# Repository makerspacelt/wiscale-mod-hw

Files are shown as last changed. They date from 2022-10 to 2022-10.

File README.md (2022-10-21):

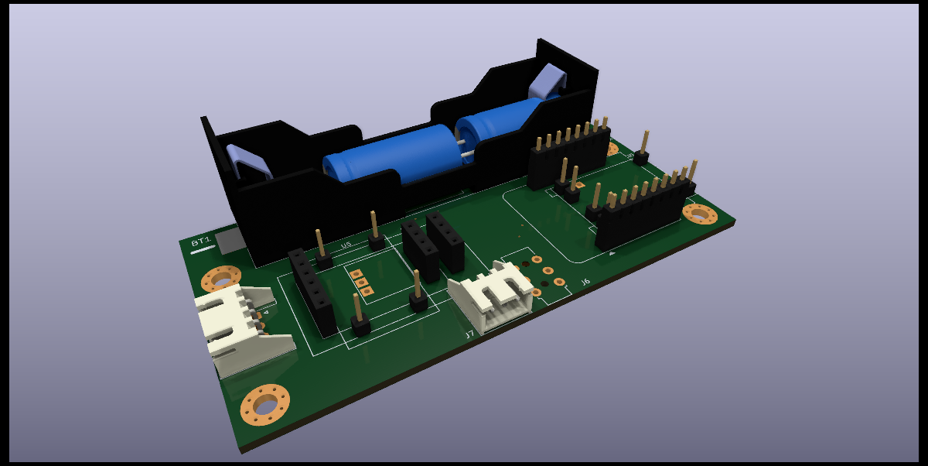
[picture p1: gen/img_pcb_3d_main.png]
PCB 3d main


This is ESP8266 and HX711 based weight monitoring device.

* Designed from commonly available aliexpress modules.
* Supports multiple load cells.
* Can be populated with 18650 battery
* Can be operated in ultra low power mode

Dev NOTE: before commit, run `./kibot.sh` to regenerate documentation, bom, gerbers and other assets.

* [schematics.pdf](gen/schematics.pdf)
* [pcb.pdf with dimensions](gen/pcb.pdf)
* [pcb_bottom.pdf for toner transfer](gen/pcb_bottom.pdf)
* [ibom.html](gen/bom_ibom.html)
* [gerbers.zip](gen/gerbers/gerbers.zip)

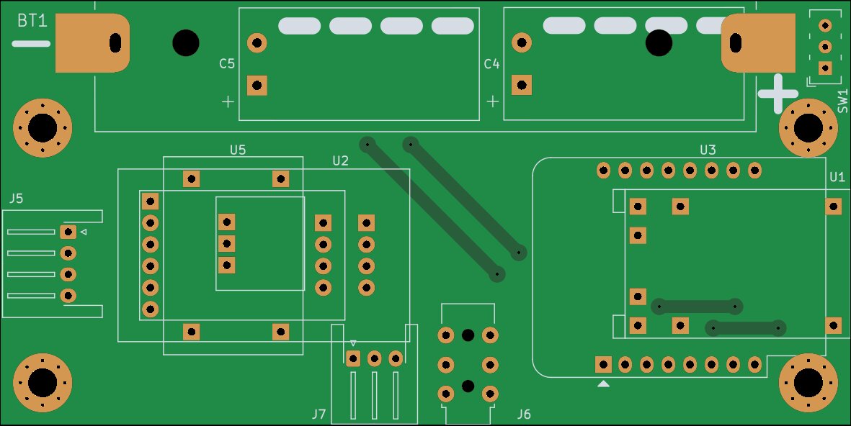
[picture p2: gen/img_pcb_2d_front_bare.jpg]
PCB 2d front bare

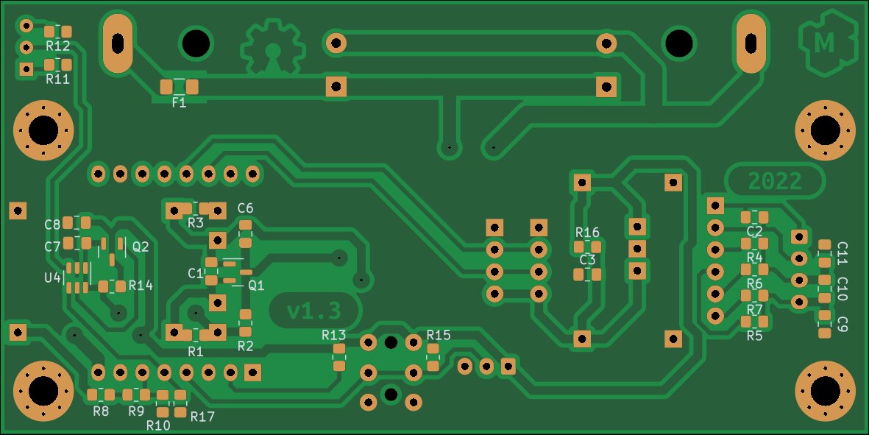
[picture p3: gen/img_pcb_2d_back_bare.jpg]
PCB 2d back bare


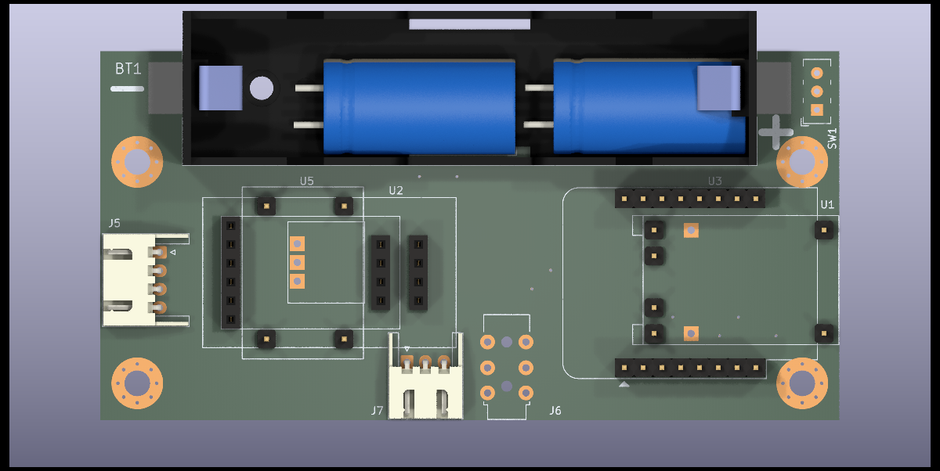
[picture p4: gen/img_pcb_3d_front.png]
PCB 3d front


## Normal operation

The circuit should be powered via a USB connector on the LiPo charger unless
battery support and low-power sleep is not used.

## Assembly and hardware configuration notes

### LiPo charger

Chargers(U1) with and without protection can be used. To use a charger without
protection that does not have separate power output pins - R1 needs to be
shorted out with a wire or zero ohms resistor.

For applications not requiring batteries whole LiPo charger section can be
omitted including components U1,Q1,BT1,F1,C1,C4,C5,C6. That requires that
the circuit be powered via a USB connector on the WeMos D1 mini module.

### Low-power sleep

A timer is equipped with selectable(SW1) wake-up settings(R11 and R12).

For applications that do not require a low-power sleep timer can be bypassed
by shorting out R14. Optionally components U3,C7,Q2,SW1,R11,R12 can be
omitted in assembly.

### Boost converter for ADC

Tests show that the circuit works down to about 2.7V without the need for
boosting voltage for ADC. Following that - the boost converter(U5) can be
omitted and R16 shorted out to bypass it.

### ADC configuration

To reduce noise on measurements capacitors(C9,C10,C11) on ADC input there
placed. As a side effect, they slow down reading settling time after weight change.
Removing these capacitors will give a fast reading but increase spread
by about 3 times.

Populating all of the R4,R5,R6,R7 links gives the ability to choose an ADC
amplifier and gain purely via software. What are the drawbacks of this
approach are unclear to me but there is an option to disconnect unused
amplifier by removing either R4 and R5 or R6 and R7 links.

## Software notes:

* keep D0 as input at all times for compatibility with older hardware (v1.0).

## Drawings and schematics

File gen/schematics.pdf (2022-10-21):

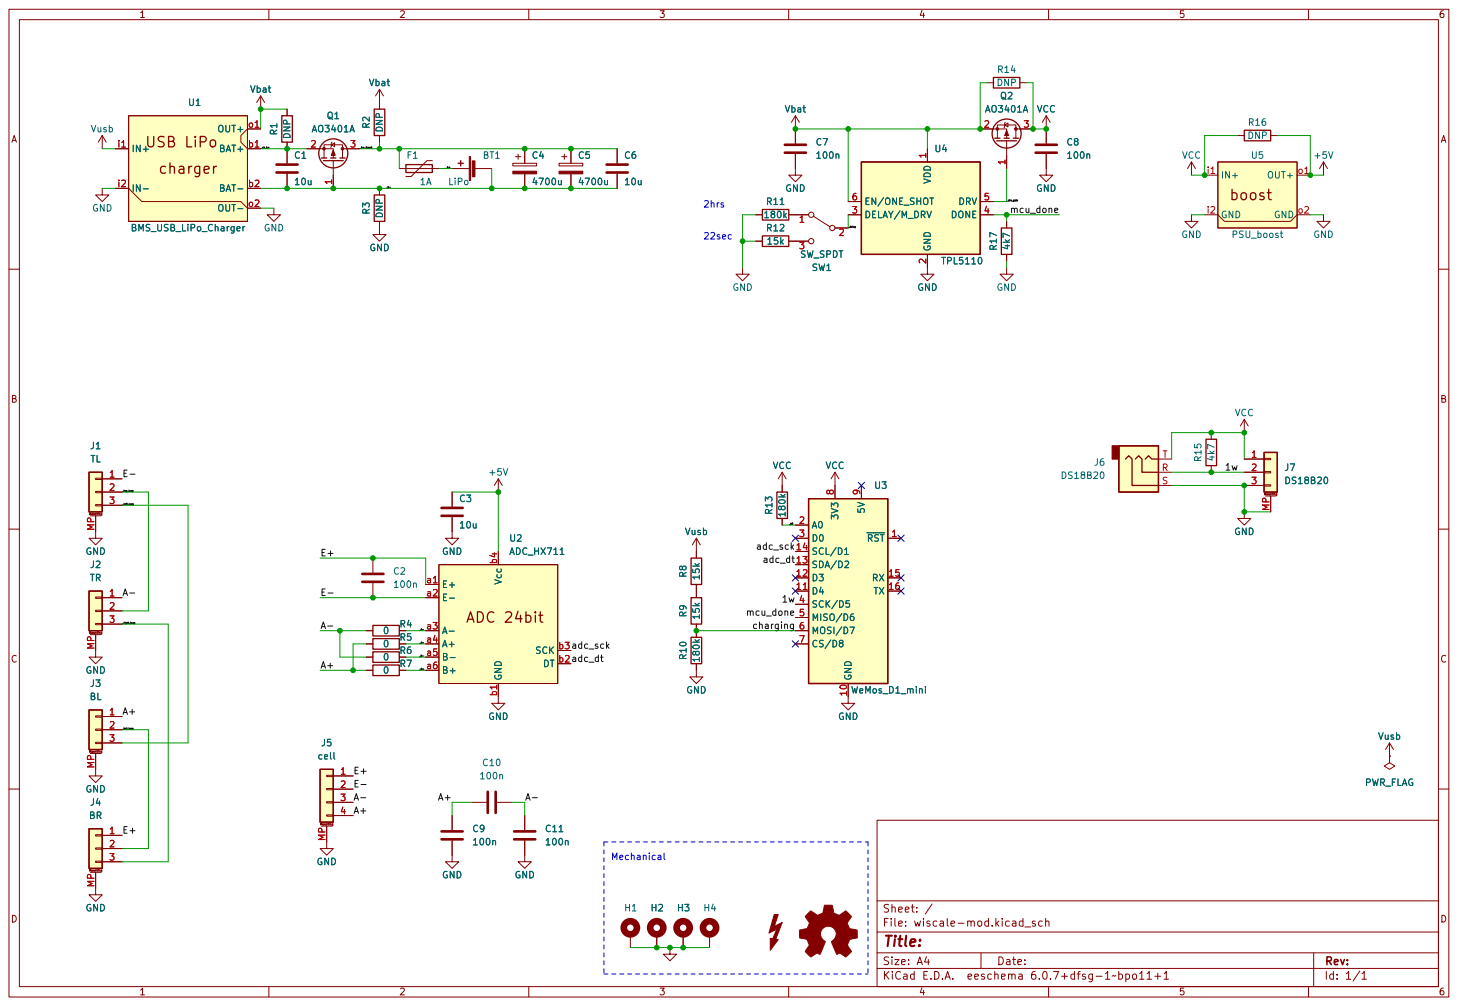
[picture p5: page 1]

2 DELAY/M_DRV 3 DONE 4 DRV 5 EN/ONE_SHOT 6 U4TPL5110 GND GND R17 4k7 C7
100n GND
2hrs 22sec Mechanical

2 DELAY/M_DRV 3 DONE 4 DRV 5 EN/ONE_SHOT 6 GND R17 4k7 C7

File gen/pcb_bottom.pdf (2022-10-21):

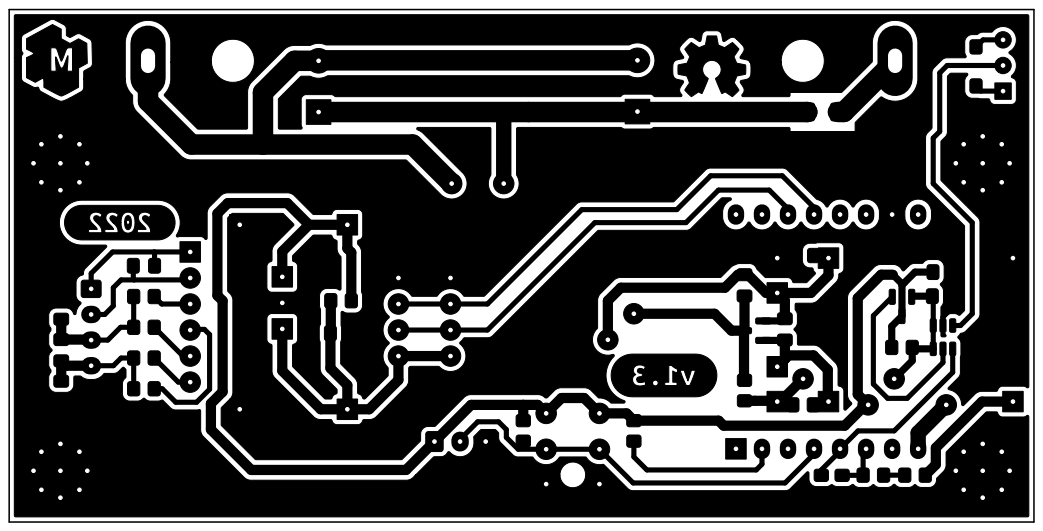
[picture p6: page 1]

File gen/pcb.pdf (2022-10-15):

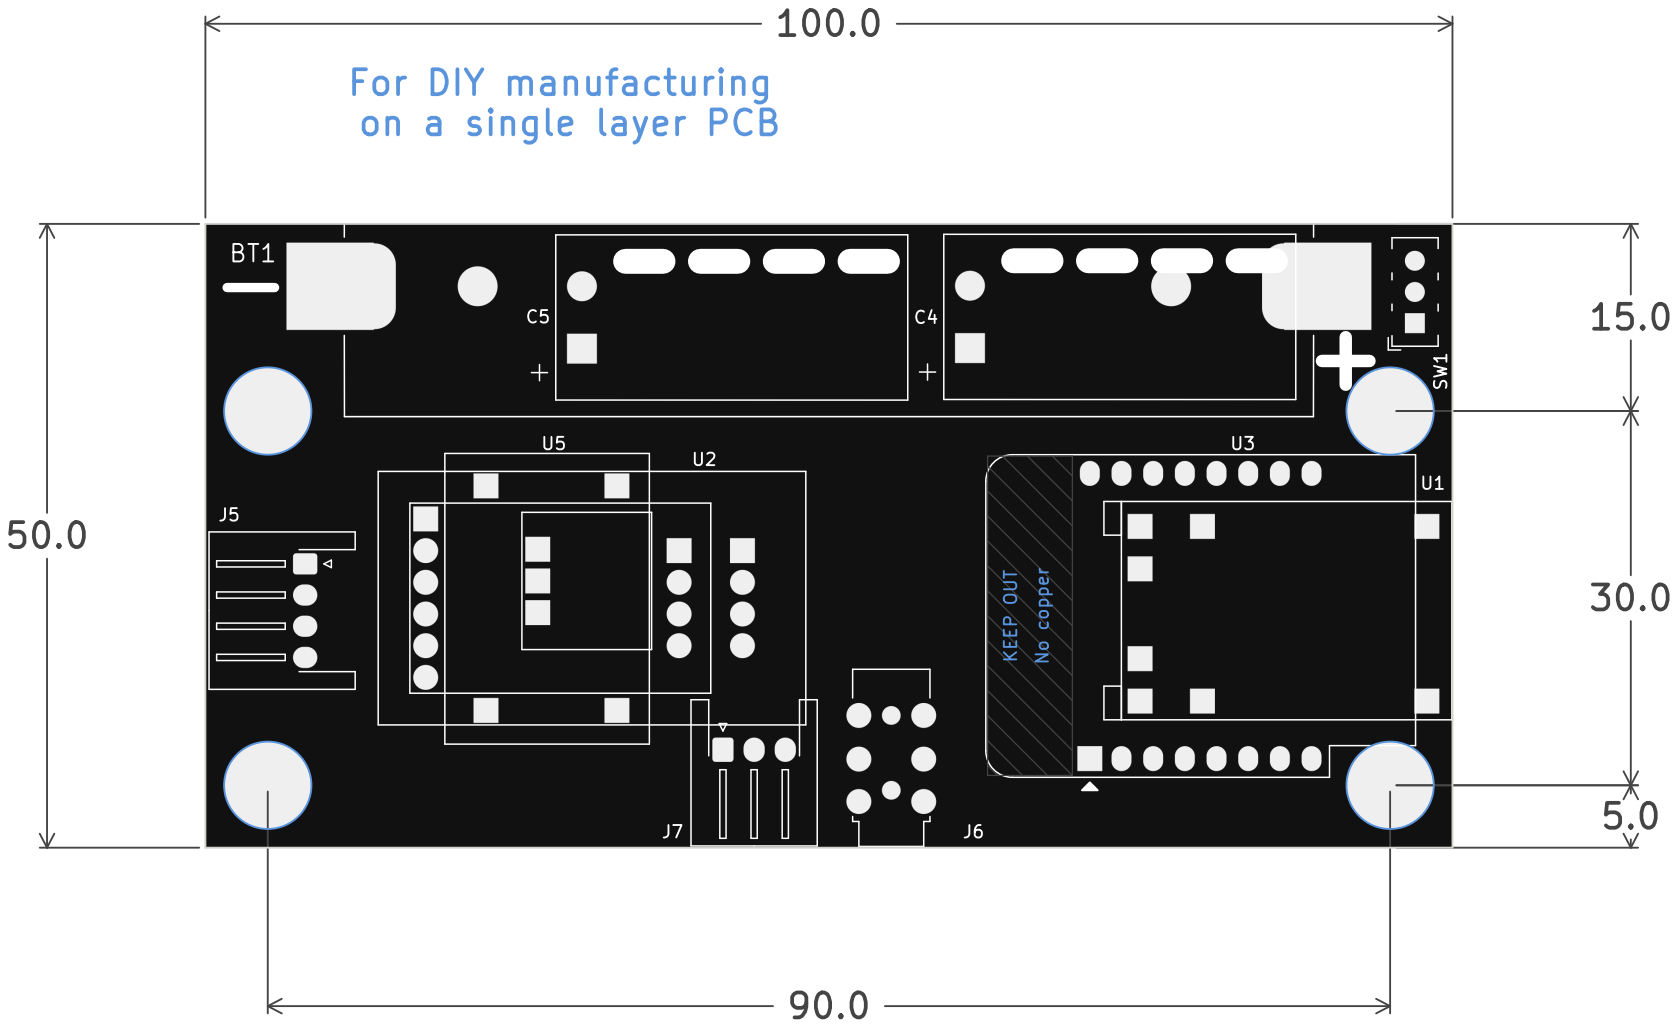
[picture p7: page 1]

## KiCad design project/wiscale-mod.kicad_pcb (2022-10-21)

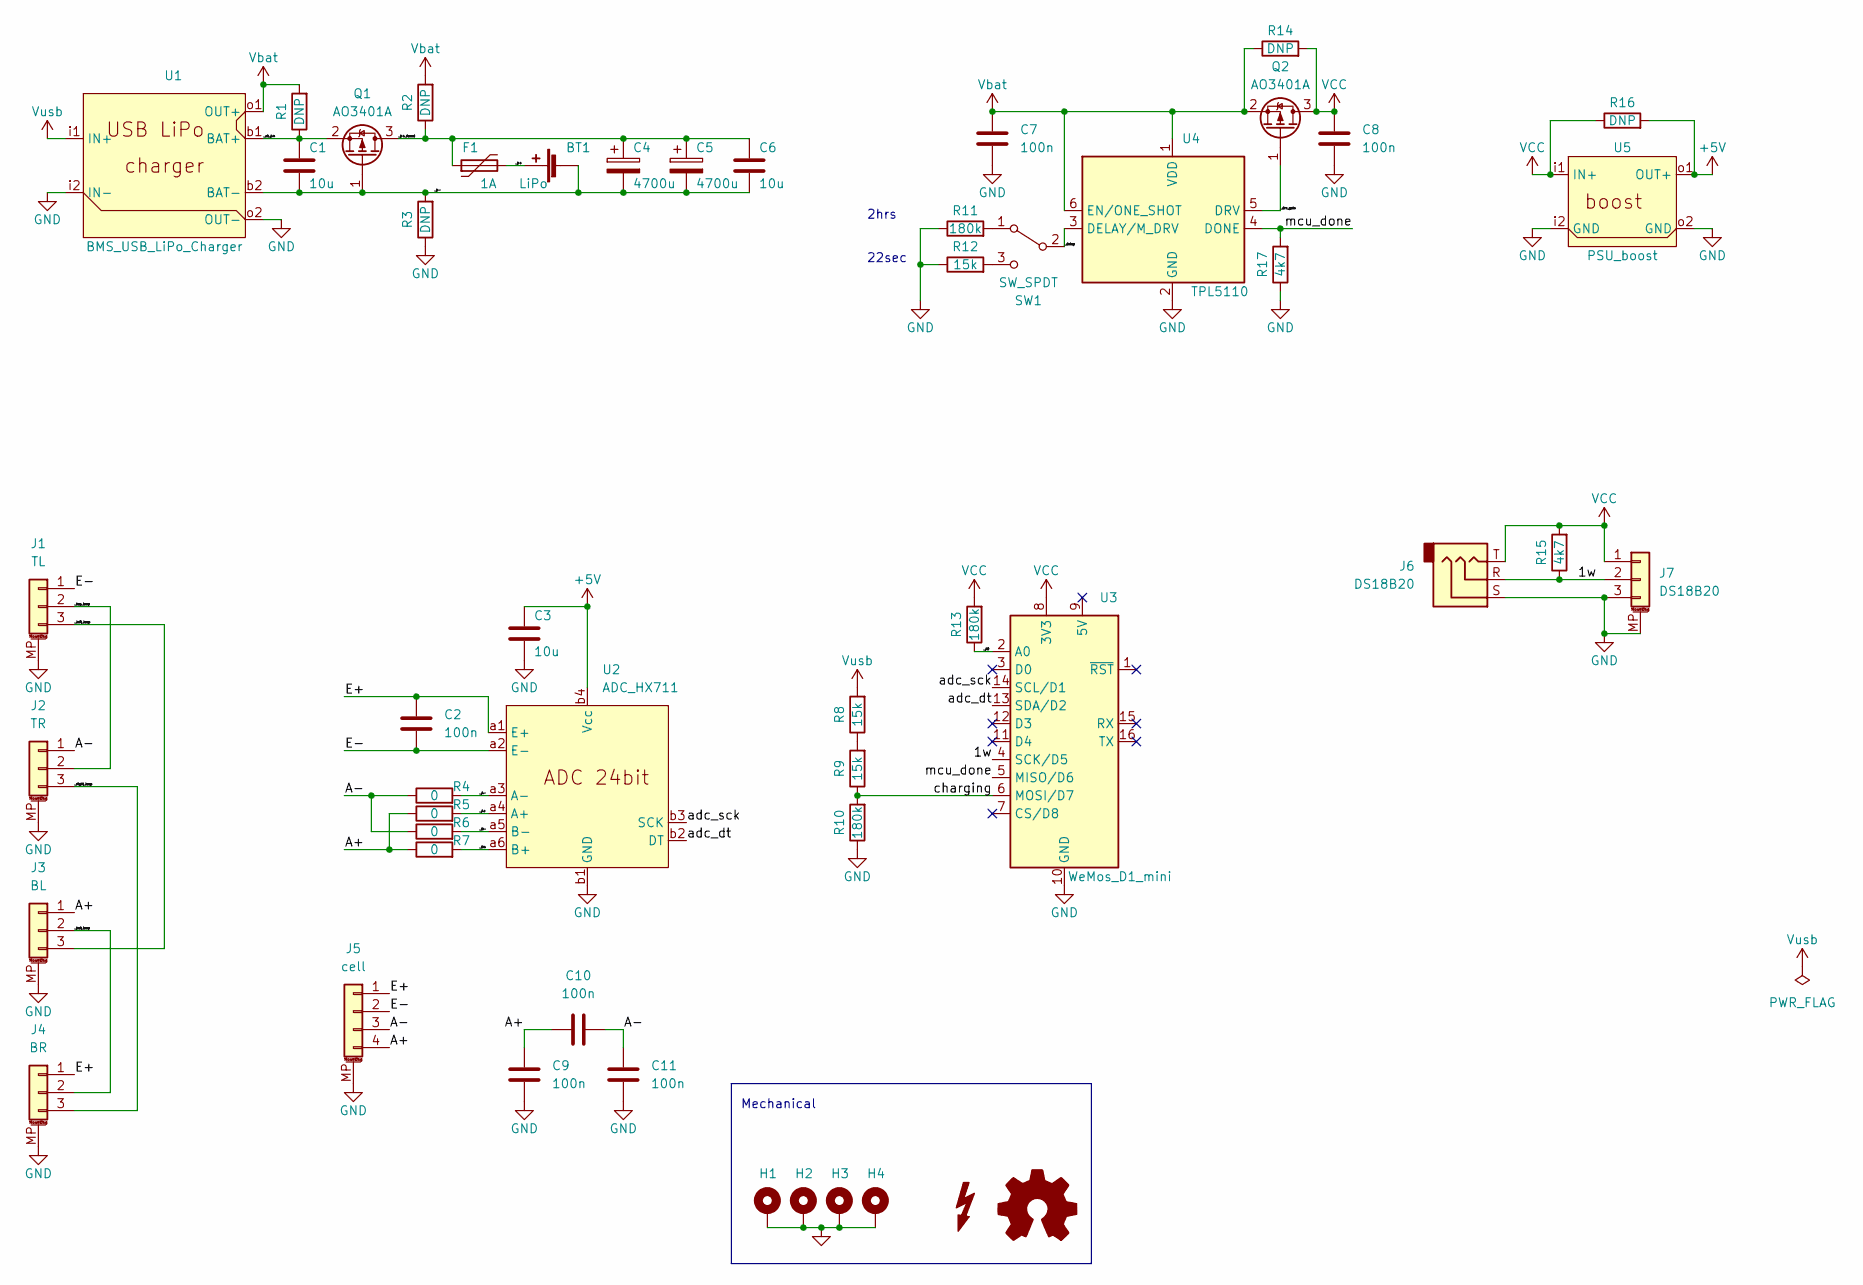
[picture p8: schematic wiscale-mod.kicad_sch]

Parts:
BT1: LiPo; BAT_BH-18650-PC
C1, C3, C6: 10u; C_0805_2012Metric_Pad1.18x1.45mm_HandSolder
C2, C7, C8, C9, C10, C11: 100n; C_0805_2012Metric_Pad1.18x1.45mm_HandSolder
C4, C5: 4700u; CP_Radial_D13.0mm_P5.00mm_L26.0mm
F1: 1A; Fuse_1206_3216Metric_Pad1.42x1.75mm_HandSolder
H1, H2, H3, H4: MountingHole_Pad; MountingHole_3.5mm_Pad_Via
J1: TL; JST_XH_S3B-XH-A-1_1x03_P2.50mm_Horizontal
J2: TR; JST_XH_S3B-XH-A-1_1x03_P2.50mm_Horizontal
J3: BL; JST_XH_S3B-XH-A-1_1x03_P2.50mm_Horizontal
J4: BR; JST_XH_S3B-XH-A-1_1x03_P2.50mm_Horizontal
J5: cell; JST_XH_S4B-XH-A-1_1x04_P2.50mm_Horizontal
J6: DS18B20; Jack_3.5mm_Horizontal
J7: DS18B20; JST_XH_S3B-XH-A-1_1x03_P2.50mm_Horizontal
LOGO1: logo_kms_small; logo_kms_small_copper
LOGO2: Logo_Open_Hardware_Small; OSHW-Symbol_6.7x6mm_Copper
Q1, Q2: AO3401A; SOT-23
R1, R2, R3, R14, R16: DNP; R_0805_2012Metric_Pad1.20x1.40mm_HandSolder
R4, R5, R6, R7: 0; R_0805_2012Metric_Pad1.20x1.40mm_HandSolder
R8, R9, R12: 15k; R_0805_2012Metric_Pad1.20x1.40mm_HandSolder
R10, R11, R13: 180k; R_0805_2012Metric_Pad1.20x1.40mm_HandSolder
R15, R17: 4k7; R_0805_2012Metric_Pad1.20x1.40mm_HandSolder
SW1: SW_SPDT; SW_E-Switch_EG1271_DPDT
U1: BMS_USB_LiPo_Charger; module_bms_usb_lipo_charger
U2: ADC_HX711; module_adc_hx711_multi
U3: WeMos_D1_mini; WEMOS_D1_mini_light
U4: TPL5110; SOT-23-6
U5: PSU_boost; module_psu_boost

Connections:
+5V: C3.2, R16.2, U2.b4 (Vcc), U5.o1 (OUT+)
/1w: J6.R, J7.2, R15.1, U3.4 (SCK/D5)
/A+: C9.2, C10.2, J3.1, J5.4, R5.1, R7.1
/A-: C10.1, C11.2, J2.1, J5.3, R4.1, R6.1
/E+: C2.2, J4.1, J5.1, U2.a1 (E+)
/E-: C2.1, J1.1, J5.2, U2.a2 (E-)
/_A0: R13.1, U3.2 (A0)
/_A+: R5.2, U2.a4 (A+)
/_A-: R4.2, U2.a3 (A-)
/_B+: R7.2, U2.a6 (B+)
/_B-: R6.2, U2.a5 (B-)
/_b+: BT1.1 (+), F1.2
/_b+_fused: C4.1, C5.1, C6.2, F1.1, Q1.3 (D), R2.1
/_b-: BT1.2 (-), C1.1, C4.2, C5.2, C6.1, Q1.1 (G), R3.2, U1.b2 (BAT-)
/_ch_b+: C1.2, Q1.2 (S), R1.1, U1.b1 (BAT+)
/_delay: SW1.2 (B), U4.3 (DELAY/M_DRV)
/_drv_gate: Q2.1 (G), U4.5 (DRV)
/adc_dt: U2.b2 (DT), U3.13 (SDA/D2)
/adc_sck: U2.b3 (SCK), U3.14 (SCL/D1)
/charging: R9.1, R10.2, U3.6 (MOSI/D7)
/mcu_done: R17.2, U3.5 (MISO/D6), U4.4 (DONE)
GND: C3.1, C7.1, C8.1, C9.1, C11.1, H1.1, H2.1, H3.1, H4.1, J1.MP (MountPin), J2.MP (MountPin), J3.MP (MountPin), J4.MP (MountPin), J5.MP (MountPin), J6.S, J7.3, J7.MP (MountPin), R3.1, R10.1, R11.1, R12.1, R17.1, U1.i2 (IN-), U1.o2 (OUT-), U2.b1 (GND), U3.10 (GND), U4.2 (GND), U5.i2 (GND), U5.o2 (GND)
unnamed: J1.2, J2.2
unnamed: J1.3, J3.3
unnamed: J2.3, J4.3
unnamed: J3.2, J4.2
unnamed: R8.1, R9.2
unnamed: R11.2, SW1.1 (A)
unnamed: R12.2, SW1.3 (C)
VCC: C8.2, J6.T, J7.1, Q2.3 (D), R13.2, R14.2, R15.2, R16.1, U3.8 (3V3), U5.i1 (IN+)
Vbat: C7.2, Q2.2 (S), R1.2, R2.2, R14.1, U1.o1 (OUT+), U4.1 (VDD), U4.6 (EN/ONE_SHOT)
Vusb: R8.2, U1.i1 (IN+)

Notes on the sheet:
2hrs 22sec
Mechanical

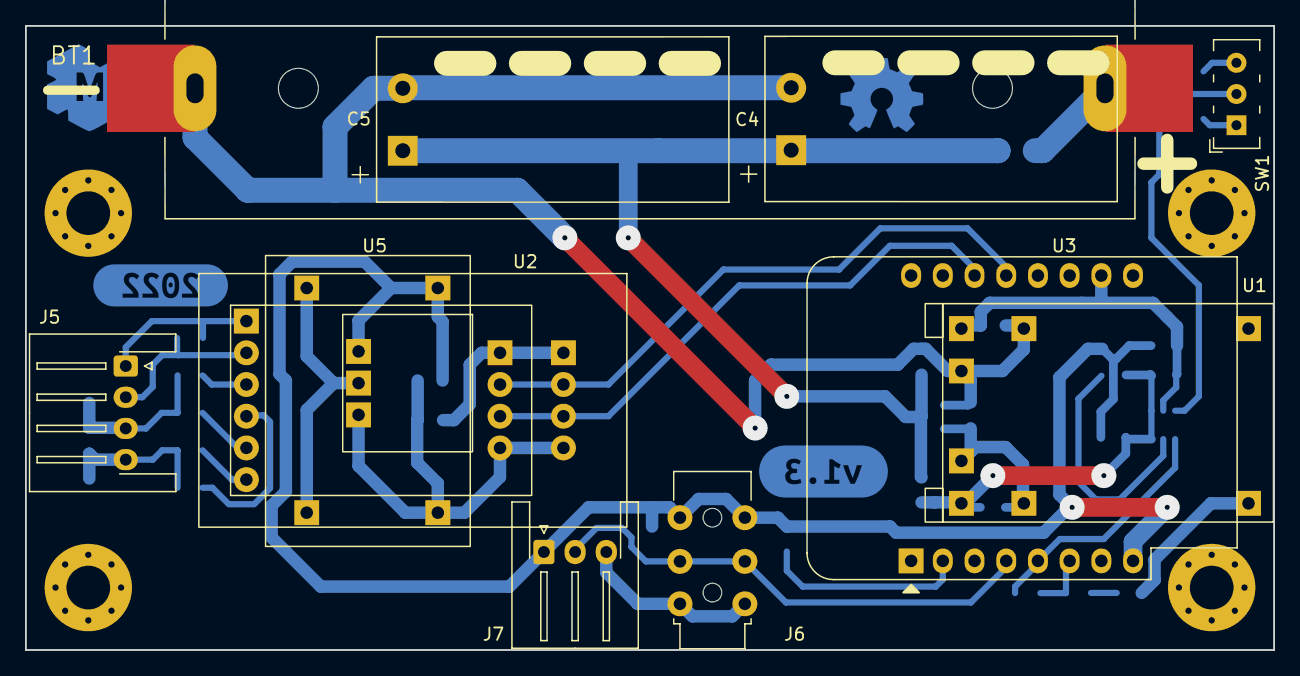
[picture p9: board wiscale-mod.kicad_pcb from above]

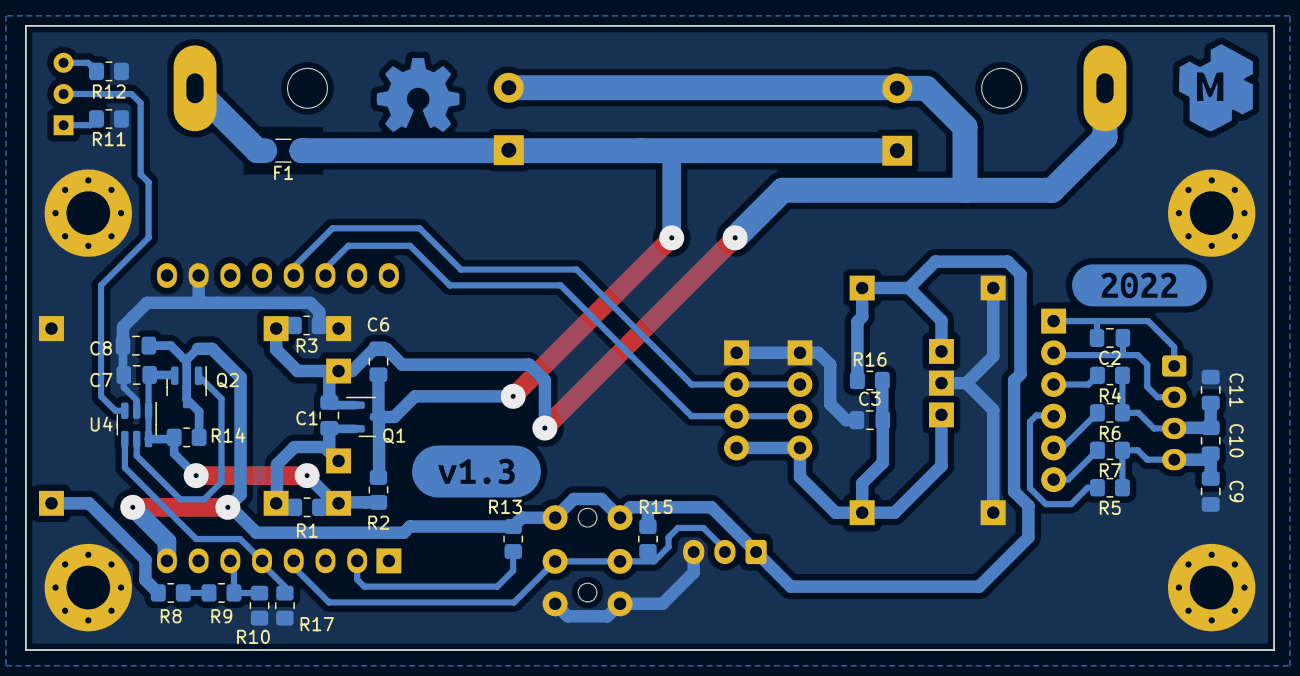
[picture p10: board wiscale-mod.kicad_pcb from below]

Board: 2 copper layers, 100.0 x 50.0 mm, 49 parts (34 on the bottom side), 28 nets.

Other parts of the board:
kibuzzard-6343E0DF: G***; kibuzzard-6343E0DF
kibuzzard-6352768B: G***; kibuzzard-6352768B

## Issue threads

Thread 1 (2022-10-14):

D0 pin cannot be used with DS18B20

AntumArk, 2022-10-14:
https://www.esp8266.com/viewtopic.php?p=61028

D0 pin is not compatible with OneWire.

Temporary fix - short D5 with D0 and set D0 to input.

Closed 2022-10-15.

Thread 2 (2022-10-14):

MCU_DONE pin should be pulled down

AntumArk, 2022-10-14:
Some noise or some capacitance influences poweron sequence, as it tries ( verified through scope) to boot up, but gets cancelled straight away. Adding 10k pull down will solve this issue.

Closed 2022-10-15.

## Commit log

2022-10-10 full project with completed pcb
    [wiscale-mod.kicad_pcb, wiscale-mod.kicad_sch]
2022-10-10 generating all the generatables
    [wiscale-mod--NPTH_map.gbr, wiscale-mod--PTH_map.gbr, wiscale-mod-B_Cu.gbr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]
2022-10-15 moving thermometer from D0 to D5. fixes #1
    [wiscale-mod.kicad_pcb, wiscale-mod.kicad_sch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]
2022-10-15 adding pull-down on MCU_DONE pin. fixes #2
    [wiscale-mod.kicad_pcb, wiscale-mod.kicad_sch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]
2022-10-21 adding caps to ADC input to average out noise
    [wiscale-mod.kicad_pcb, wiscale-mod.kicad_sch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]
